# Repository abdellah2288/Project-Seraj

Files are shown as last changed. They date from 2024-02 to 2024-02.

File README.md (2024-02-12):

# Project-Seraj
An Open source development board for EHTP ElectroPower's Circuit Jam Hackathon ([Schematics](https://github.com/abdellah2288/Project-Seraj/files/14251244/seraj.pdf))

seraj_dev_board

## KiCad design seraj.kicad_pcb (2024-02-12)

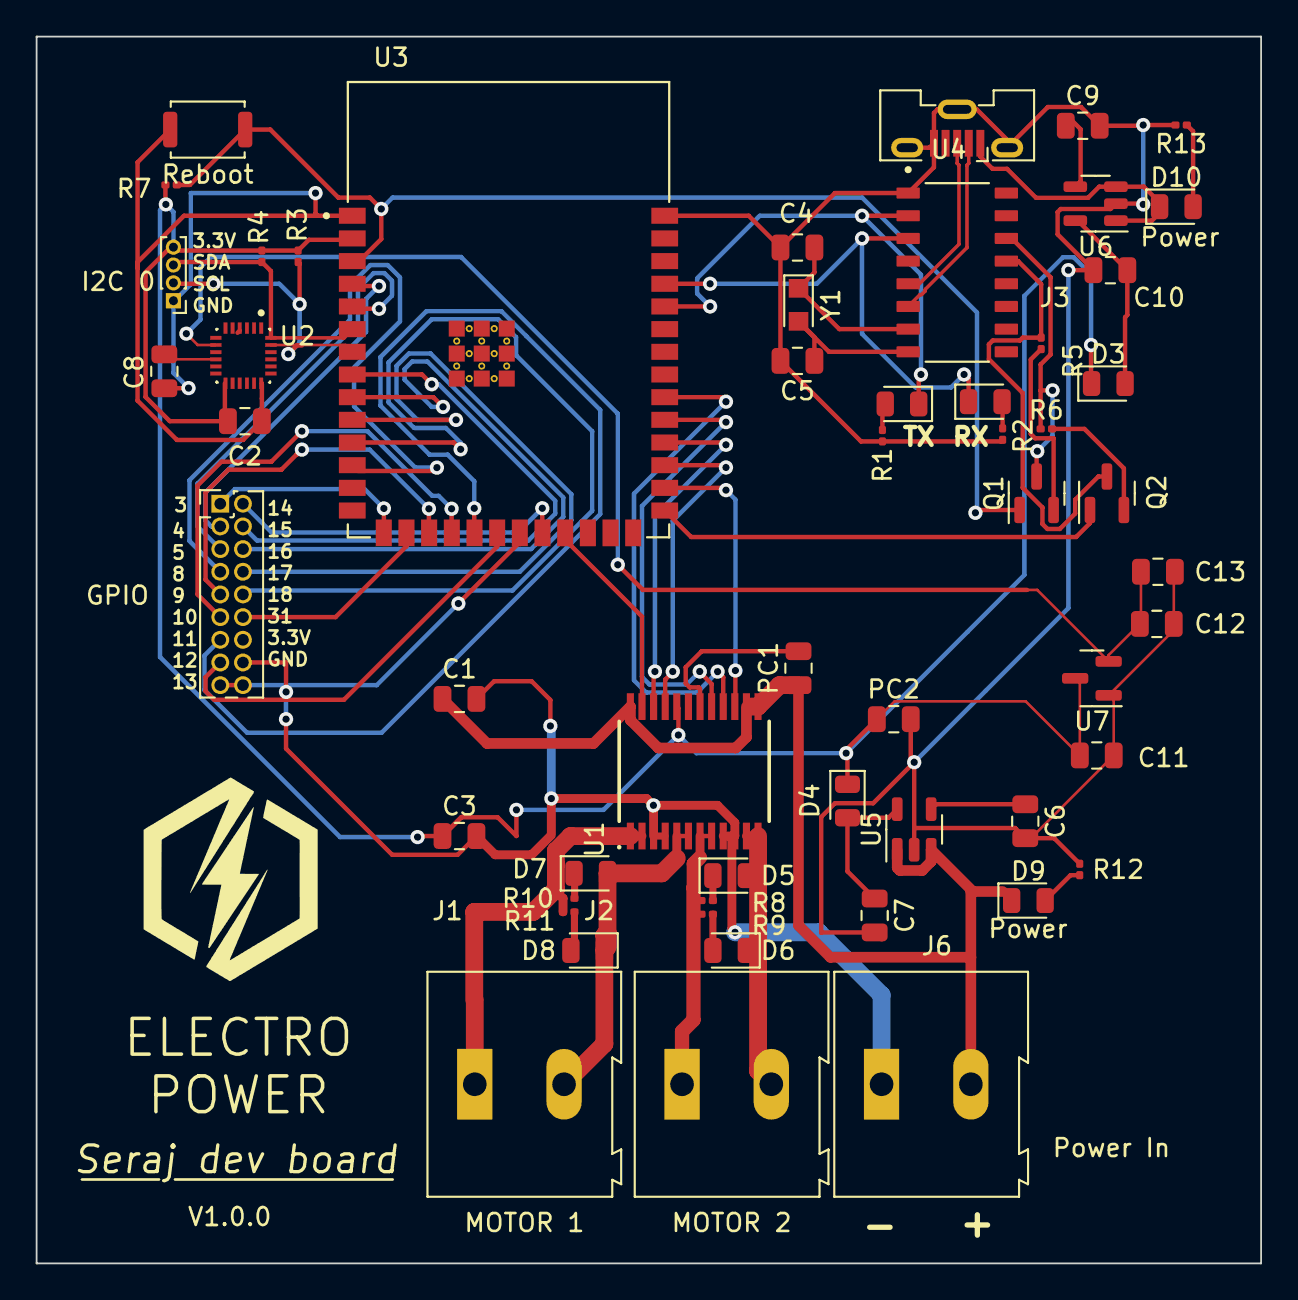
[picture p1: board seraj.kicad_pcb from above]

Board: 2 copper layers, 68.6 x 68.7 mm, 55 parts (0 on the bottom side), 55 nets.

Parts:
C1, C2, C3, C8, C13: 0.1uF; C_0805_2012Metric
C4, C5: 22pF; C_0805_2012Metric
C6, C9: 470pF; C_0805_2012Metric
C7, C10: 2.2uF; C_0805_2012Metric
C11, C12: 1uF; C_0805_2012Metric
D1, D2, D5, D6, D7, D8, D9, D10: LED; LED_0805_2012Metric
D3, D4: 1N5819HW-7-F; D_0805_2012Metric
J1: MOTOR 1; TerminalBlock_Altech_AK300-2_P5.00mm
J2: MOTOR 2; TerminalBlock_Altech_AK300-2_P5.00mm
J3: Serial; USB_Micro-B_Molex-105133-0031
J4: I2C 0; PinHeader_1x04_P1.00mm_Vertical
J5: Conn_2Rows-17Pins; PinHeader_2x09_P1.27mm_Vertical
J6: Power In; TerminalBlock_Altech_AK300-2_P5.00mm
PC1, PC2: 10uF; C_0805_2012Metric
Q1, Q2: NPN; SOT-23
R1, R2, R3, R4, R7: 4.7k; R_0201_0603Metric
R5, R6: 12k; R_0201_0603Metric
R8, R9, R10, R11, R12, R13: 10k; R_0201_0603Metric
SW1: Reboot; SW_Push_SPST_NO_Alps_SKRK
U1: TB6612FNG_C_8_EL; SOP65P760X160-24N
U2: ICM-20948; QFN40P300X300X105-24N
U3: ESP32-S3-WROOM-1-N8R8; XCVR_ESP32S3WROOM1N8R8
U4: CH340G; SOIC127P600X180-16N
U5, U6: MIC5219-3.6YM5; SOT-23-5
U7: MCP1700x-120xxTT; SOT-23
Y1: 12MHz; Crystal_SMD_2012-2Pin_2.0x1.2mm_HandSoldering

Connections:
+1V8: C12.1, C13.1, U2.8 (VDDIO), U7.2 (VO)
+3.3V: C2.1, C3.1, C11.1, D3.1 (K), D4.1 (K), J4.4, PC2.1, R3.1, R4.1, R7.1, U1.20 (VCC), U2.13 (VDD), U3.2 (3V3), U7.3 (VI)
+12V: C1.1, D9.1 (K), J6.2, PC1.1, U1.13 (VM2), U1.14 (VM3), U1.24 (VM1), U5.1 (IN), U5.3 (EN)
/AIN1: U1.21 (AIN1), U3.29 (IO36)
/AIN2: U1.22 (AIN2), U3.30 (IO37)
/BIN1: U1.17 (BIN1), U3.31 (IO38)
/BIN2: U1.16 (BIN2), U3.32 (IO39)
/BOOT: Q2.1 (C), U3.27 (IO0)
/DTR#: Q2.3 (E), R5.1, U4.13 (~DTR)
/EN: Q1.1 (C), R7.2, SW1.2, U3.3 (EN)
/GPIO3: J5.1, U3.15 (IO3)
/GPIO4: J5.3, U3.4 (IO4)
/GPIO5: J5.5, U3.5 (IO5)
/GPIO8: J5.7, U3.12 (IO8)
/GPIO9: J5.9, U3.17 (IO9)
/GPIO10: J5.11, U3.18 (IO10)
/GPIO11: J5.13, U3.19 (IO11)
/GPIO14: J5.2, U3.22 (IO14)
/GPIO15: J5.4, U3.8 (IO15)
/GPIO16: J5.6, U3.9 (IO16)
/GPIO17: J5.8, U3.10 (IO17)
/GPIO18: J5.10, U3.11 (IO18)
/GPIO31: J5.12, U3.16 (IO46)
/PWMA: U1.23 (PWMA), U3.23 (IO21)
/PWMB: U1.15 (PWMB), U3.28 (IO35)
/RTS#: Q1.3 (E), R6.1, U4.14 (~RTS)
/SCL_0: J4.2, R3.2, U2.23 (SCL/SCLK), U3.7 (IO7)
/SDA_0: J4.3, R4.2, U2.24 (SDA/SDI), U3.6 (IO6)
/Serial_D+: J3.3 (D+), U4.5 (UD+)
/Serial_D-: J3.2 (D-), U4.6 (UD-)
/Serial_RX: D2.1 (K), U3.37 (TXD0), U4.3 (RXD)
/Serial_TX: D1.1 (K), U3.36 (RXD0), U4.2 (TXD)
GND: C1.2, C2.2, C3.2, C4.2, C5.2, C6.2, C7.2, C8.2, C9.2, C10.2, C11.2, C12.2, C13.2, J3.5 (GND), J3.6 (Shield), J4.1, J5.15, J5.16, J5.17, J5.18, J6.1, PC1.2, PC2.2, R1.2, R2.2, R12.2, R13.2, SW1.1, U1.3 (PGND1@1), U1.4 (PGND1@2), U1.9 (PGND2@1), U1.10 (PGND2@2), U1.18 (GND), U2.18 (GND), U3.1 (GND), U3.20 (IO12), U3.21 (IO13), U3.40 (GND), U3.41_1 (GND), U3.41_2 (GND), U3.41_3 (GND), U3.41_4 (GND), U3.41_5 (GND), U3.41_6 (GND), U3.41_7 (GND), U3.41_8 (GND), U3.41_9 (GND), U4.1 (GND), U5.2 (GND), U6.2 (GND), U7.1 (GND)
unnamed: D1.2 (A), R1.1
unnamed: D2.2 (A), R2.1
unnamed: C10.1, D3.2 (A), U6.5 (OUT)
unnamed: C7.1, D4.2 (A), U5.5 (OUT)
unnamed: D5.2 (A), D6.1 (K), J2.2, U1.11 (BO1@1), U1.12 (BO1@2)
unnamed: D5.1 (K), R8.2
unnamed: D6.2 (A), R9.2
unnamed: D7.2 (A), D8.1 (K), J1.2, U1.5 (AO2@1), U1.6 (AO2@2)
unnamed: D7.1 (K), R10.2
unnamed: D8.2 (A), R11.2
unnamed: D9.2 (A), R12.1
unnamed: D10.2 (A), R13.1
unnamed: J1.1, R10.1, R11.1, U1.1 (AO1@1), U1.2 (AO1@2)
unnamed: J2.1, R8.1, R9.1, U1.7 (BO2@1), U1.8 (BO2@2)
unnamed: Q1.2 (B), R5.2
unnamed: Q2.2 (B), R6.2
unnamed: C8.1, U2.10 (REGOUT)
unnamed: C4.1, U4.7 (XI), Y1.1
unnamed: C5.1, U4.8 (XO), Y1.2
unnamed: C6.1, U5.4 (BP)
unnamed: C9.1, U6.4 (BP)
VBUS: D10.1 (K), J3.1 (VBUS), U6.1 (IN), U6.3 (EN)
